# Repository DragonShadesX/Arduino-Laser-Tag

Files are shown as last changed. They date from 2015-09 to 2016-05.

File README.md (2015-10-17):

Arduino-Laser-Tag
=================

A repository for my arduino laser tag files

The idea is to create a laser tag system comparable to commercial grade systems found at arenas.

ltag_simple_tagger is a proof of concept build and is for debugging.

ltag_ fire/hit _test are also mainly for debugging.

ltag_custom_your_name_here is the only working full system code.
It is very limited and works, but it doesn't do a whole lot.  Documentation for it is in it's files.

ltag_custom_dragonshadesx is a working build of my tagger.  
So far so good.  There's a lot of comments removed right now because it's still a work in progress and I don't like sorting through it all.
Also because it's 5 in the morning and I want a backup so I can sleep well knowing my code is saved.

libraries is the local libraries you'll need for the files, the only library there right now is from:
http://www.pjrc.com/teensy/td_libs_IRremote.html
This is a modified version of the library originally found at
http://www.righto.com/2009/08/multi-protocol-infrared-remote-library.html
You'll need to replace whatever libraries you have (IRRemoteRobot or whatever) with this if you're using a standard arduino (uno, due, etc).
If you're using a teensy it should come with it's own libraries, just make sure to install them when you run the teensyduino addon.

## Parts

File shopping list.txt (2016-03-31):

	 -s teensy x5 (4tag, 2base, 1admin)
	 -s audio shield x4
	 -s audio amps

 -m 3.3vreg
 -s diodes
	 -a usd card
	 -m speakers x8
 -m shift registers x16
 -m shift registers in x4
	 -s rgb led x64
 -m resistors for LEDs xlots (for rgb, bar graphs, and 7segs)
 -s led bar graphs xseveral (Alan -blue green) (Jake -blue yellow)
 -s led 7 segs xfew
	 -m irleds x7
	 -m irrecvs x27
 -s limit switches x8
 -m usb 3.o type a ports x12 
	 -s lcd display x1
	 -o d-pad x1
	 -a rechargables x4
 -m AA holder (single) x5
	 -o AAs x8
	 -s pager motors x4
	 -m irf520-510 x7
 -a usb 3.0 3ft cables (type a - type a)
usb micro plug
 -s 5pin ribbon cable

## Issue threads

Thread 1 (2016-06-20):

EDA replacements by a free one

psykauze, 2016-06-20:
Dear DragonShadesX,

This project is very interesting and I would like to participate on this but I'm not in love with Eagle (due to it's proprietary license).

So, I want to know if you're planning to use an other EDA.

I'm used to use KiCad (due to it's similarities with Eagle) but there's also others tools. Here, 3 tools:
- gEDA: Full suite of electronic tools. It have a lot of features and also a great simulating tool (ngspice).
- KiCad: Eagle clone with a lot of libraries. There's also a 3D viewer for PCB. For simulation it can use any "spice-like" tool (like ngspice from gEDA project)
- Fritzing: There's a "breadboard" tool. It seems it can't simulate anything but I'm not sure.

Which one do you prefer ? Would you want some help for the conversion ?

Sincerely.

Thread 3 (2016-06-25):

LED Control

DragonShadesX, 2016-06-25:
Something is odd with controlling the RGB LEDs.  Honestly don't know exactly what, could never get the blue or green to light up independently.  Red LED doesn't want to light up.  All can be lit manually, so my best guess is a fried shift register or torn trace on the board but I don't have spare to test with right now.  Also possible I have something wrong in the code, but I don't know.

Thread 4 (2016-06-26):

Code: Phoenix Compatibility

DragonShadesX, 2016-06-26:
It takes 1-3 seconds between shots for the library to "reset" and fire the correct data sequence.  If you fire too fast it just sends junk data.  I'm not sure why as the Phoenix Compatible Library was not written by us.  Fix is probably to re-write or throw in a delay as a short term fix until someone wants to figure out why.  Phoenix compatibility was a side goal though, so this is low priority.

psykauze, 2016-06-27:
I don't know if it is related, but your friend GranTotem use an old version of IRremote but last year a "send loops coding error" was fixed.

The actual IRremote project is here. https://github.com/z3t0/Arduino-IRremote Hope this will fix the issue.

DragonShadesX, 2016-06-29:
I started with that version, but we have to use a specific version that is compatible with the Teensy so we can't just go back to that.  The 1-3 second delay is a known issue with communicating with the Phoenix and I haven't seen it any other time.  Both of these mean just using that library won't fix the problem.

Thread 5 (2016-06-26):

Hardware: Phoenix Compatibility

DragonShadesX, 2016-06-26:
For some reason, the hardware in the Phoenix is only triggered when the custom tagger is within a few feet of the Phoenix.  Best guess is that the IR LED is not bright enough.  This could be fixed with a stronger IR LED (not recommended) or an IR-Permeable lens to focus the light and condense the beam, though this means the user will have to be much more accurate.  This is low priority since Phoenix compatibility is not a main feature.

psykauze, 2016-06-26:
You can focusing the IR beam by using a lens.

I think this is possible with a 45mm long black tube, a lens from Google Cardboard (<$3) and a TSAL6100 (<$1). This will focus the beam into a 16mm diameter cilinder.

If you use a TSAL6200 you should have a "45mm focal" lens of more than 26mm diameter. The diameter of the beam will be 26,3mm diameter.

DragonShadesX, 2016-06-26:
I know, I've done the math and checked the numbers with a few cheap lenses.  Testing with the Phoenix taggers and the TSAL6100 with no lenses gave me the same performance with respect to how far off the target I could aim and still have the target register a hit.

Also, consider that your target (on the Phoenix) is a small, moving, ~3cm diameter dome, and with a lens/beam setup you are trying to hit it with a 2.6cm wide beam at ranges of 3-40m(max range I was able to test).  For a normal person that is near impossible, never mind when the target is a 4mm x 4mm square on the vest (if the player is trying to tag another player using the custom system).

psykauze, 2016-06-27:
You're right, I've forgot the Phoenix system use a single shot gameplay.
1) Maybe if the Soft tries to spam the shoot during ~500ms the accuracy will not improve but there's more chances to hit.
2) Reducing the beam to 10° with a lens will improve range and the need of accuracy should be correct.
3) Use of laser dot ? (In case of 13mm cilinder beam. Is it cheating ???)

psykauze, 2016-06-27:
Also, which wavelength use the Phoenix system ? Maybe it is more effective with a 850nm IR than a 940nm.

psykauze, 2016-06-27:
You could also mesure the Phoenix beam by shooting on a white board and view it with a digital camera.

psykauze, 2016-06-27:
Here some patents about Phoenix toys:
- http://www.google.com/patents/US5904621 Protocol frequency is about 38kHz
- http://www.google.com/patents/US6302796 The current drawn by the IR-LED of this presented gun is at about 3Amps. (300ft range)
- http://www.google.com/patents/US5672108 This gun use a EL-8L IR Led that emits a 940nm light. Also, this patent recommends a beam of 4°.

DragonShadesX, 2016-06-29:
First comment:
1) It doesn't send correct data so you can't hit the target, not sure what that has to do with accuracy.
2) The LED has a viewing angle of 10 degrees already.
3) If you feel like it.  I was going to avoid it because point lasers at the shoulder plates is dangerously close to someone's eyes.
Third comment:
I made some night vision goggles to help test with the project, they worked well.  Most digital cameras block IR since it messes with the pictures.
Fourth comment:
The EL-8L is a 30 degree .1 amp LED.  Also amps =/= range, and there is no way that these work at 300ft.  In testing the Phoenix dropped off at about 80ft in outdoor environments with relatively fresh batteries (~30 mins light useage).  38kHz is also pretty common, though the Phoenix do use it.
Those patents are also from almost 20 years ago and not likely to be very relevant to the Phoenix.  The third seems to have preliminary designs for the Laser Tag Team Ops gear, which is the Phoenix's predecessor (and it's sorta compatible too).  I wouldn't bother with the patents.

psykauze, 2016-06-29:
Sorry for the spam on this thread.

I've seen that the Phoenix LazerTag was based to the Tiger/Hasbro systems that was commercialized in 2004 (for Team Ops) maybe before. So it's why I've checked some technical informations about these systems also from patents.

I understand that the patents is not the reality, but they give us some clues on how the system works.

In the second patent, there's no info about the IR-LED or beam but the schematics show the IR-LED powered by a 6V battery, limited by a 1ohm resistor and drived by a bipolar transistor, so if I consider a voltage drop of 3V for transistor and IR diode, the peak current consumption is about 3Amps and can explain the 300ft range. (I know I can't be precise for the voltage drop. I've found the Vdrop should be just a little less than 4V, so the current should be a little higher than 2Amps peak.).

The third patent give some recommendations like the beam cone of 4° (adjusted by a lens) and the LED used in this patent (the EL-8L). For the last thing, we can conclude the system use a 940nm IR protocol.

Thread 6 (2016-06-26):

Hardware: Power Requirements

DragonShadesX, 2016-06-26:
The system only works with an Arduino Teensy 3.2 and 5V battery pack plugged into the Teensy.  The chosen Voltage Regulator does not output enough amps to power the Teensy and all the LEDs.  While we didn't notice any brown-outs the LEDs were dim and we barely tested it with the VReg after that.  A new, higher power VReg should fix the issue, though the socket for it might need to change.

psykauze, 2016-06-27:
Leds and IR-led don't need a voltage regulated power, just a current limitation (like a resistor).
I know you're using the integrated Teensy output pin current limitation to drive your leds but you can increase (or decrease) the leds number without burning Leds, Vreg or Teensy if you choose to drive transistors.

DragonShadesX, 2016-06-29:
LEDs will draw as much current as they need if you give them the proper voltage with enough current, so current limitation is not needed.
All LEDs are toggled by transistor (IRF5X0 or shift register), the only pin on the Teensy that is used is the 3.3v regulated output for power.

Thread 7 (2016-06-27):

Hardware: Reverse voltage protection

psykauze, 2016-06-27:
I've seen two diodes at the Power connector. If the purpose of those diode is to protect from a reverse polarity, one diode is enough.

You could also use a "poka-yoke" connector to prevent users errors.

Also, "I think" all the parts used on the board is y et reversed protected (Teensy, Leds, etc...).

DragonShadesX, 2016-06-29:
Yes we could probably use one diode, yes we could use a connector but the idea was to solder on a 9V battery connector so we didn't bother to add connector.
Not sure about the reverse protection, but either way too high voltage applied backwards will fry/brick them so we decided to make it foolproof.

psykauze, 2016-06-29:
What do you mean by "too high voltage applied backwards" ?

Do you mean you want to protect the battery of reverse current ? In this case, I still think one diode is enough and you'll gain some precious Watts (and battery capacity).

DragonShadesX, 2016-06-29:
One is probably enough, my thinking was that I wanted to make it foolproof so if someone connected the battery backwards the instant potential across the LEDs/powering the Teensy in the wrong direction couldn't damage anything.  I already bricked two Arduinos in other projects under normal usage (probably a bad power supply) and I didn't have time to get spares, so I didn't want to take chances.
The other reason is because this whole project was put together by a few people who had never really done this before, so I wanted to build in some safeties for if/when something went wrong (especially near the batteries in case we switched to LiPos).  For a final version?  Might take it out after I do some more research.  For a prototype and learning experience?  I had a bunch of those diodes on hand and it didn't cost me anything, so I figured why not.

psykauze, 2016-06-29:
Ok, not a problem. It's not a real issue because it should work like this. I'm just used to see only one diode to prevent "reverse polarity" issues. It's only because you will have a 2V Vdrop.

Also 1N4001 diodes are not very good (but very cheap). If you want to tune this part, you can use a Schottky rectifier diode as a replacement.

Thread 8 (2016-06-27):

[Enhancement]LCD screen support.

psykauze, 2016-06-27:
This is a feature request for more visibility.

DragonShadesX, 2016-06-29:
Not sure I understand?

psykauze, 2016-06-29:
It's just because the Phoenix Lazer Tag system has a LCD screen for configuration and display. This is a low priority.

DragonShadesX, 2016-06-29:
The Team Ops gear does, the Phoenix has two 5-segment LED Bar Graphs.

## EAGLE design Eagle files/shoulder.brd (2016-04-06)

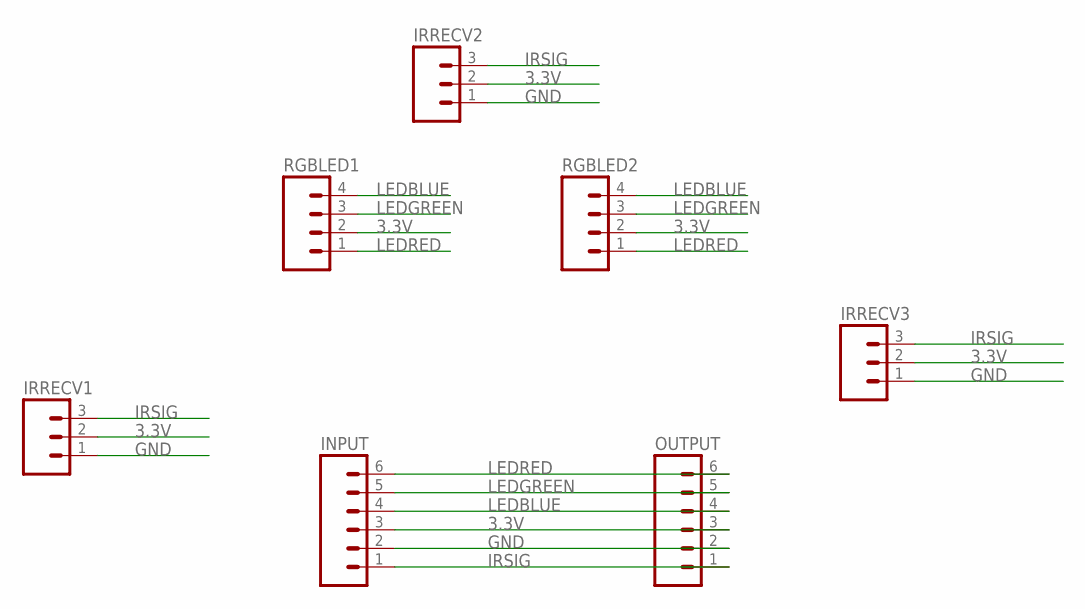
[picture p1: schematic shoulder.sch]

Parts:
INPUT: M06SILK_FEMALE_PTH; 1X06
IRRECV1, IRRECV2, IRRECV3: M03PTH; 1X03
OUTPUT: M06SILK_FEMALE_PTH; 1X06
RGBLED1, RGBLED2: M04PTH; 1X04

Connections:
3.3V: INPUT.3, IRRECV1.2, IRRECV2.2, IRRECV3.2, OUTPUT.3, RGBLED1.2, RGBLED2.2
GND: INPUT.2, IRRECV1.1, IRRECV2.1, IRRECV3.1, OUTPUT.2
IRSIG: INPUT.1, IRRECV1.3, IRRECV2.3, IRRECV3.3, OUTPUT.1
LEDBLUE: INPUT.4, OUTPUT.4, RGBLED1.4, RGBLED2.4
LEDGREEN: INPUT.5, OUTPUT.5, RGBLED1.3, RGBLED2.3
LEDRED: INPUT.6, OUTPUT.6, RGBLED1.1, RGBLED2.1

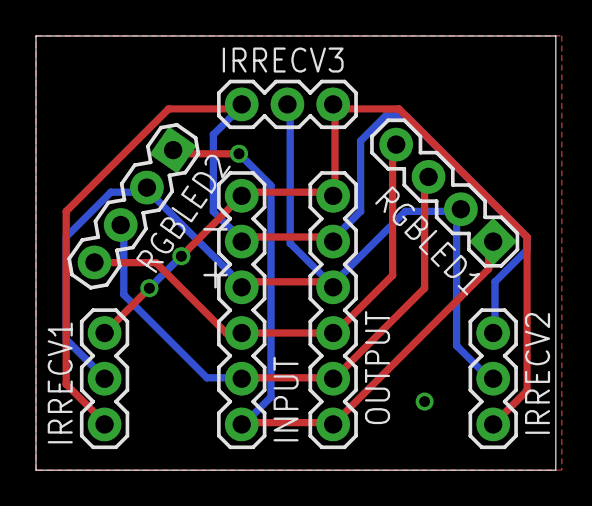
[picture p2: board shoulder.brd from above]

Board: 2 copper layers, 28.9 x 24.1 mm, 7 parts (0 on the bottom side), 6 nets.

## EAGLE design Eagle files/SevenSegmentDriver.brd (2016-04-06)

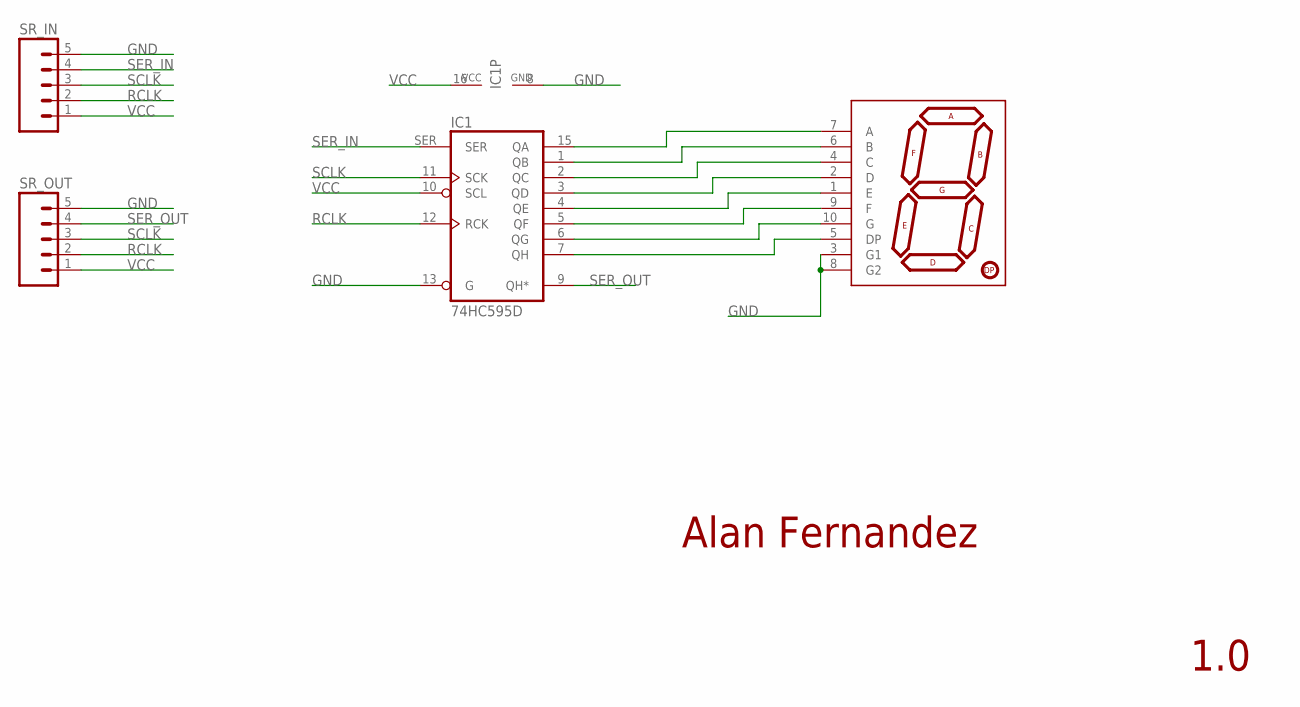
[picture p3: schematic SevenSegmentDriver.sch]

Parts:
IC1: 74HC595D; SO16
SR_IN: M05PTH; 1X05
SR_OUT: M05PTH; 1X05
U$1: 7-SEGMENT-DISPLAY-1"-REDEZ; 7-SEGMENT-1"PTH-EZ

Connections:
GND: IC1.8 (GND), IC1.13 (G), SR_IN.5, SR_OUT.5, U$1.3 (G1), U$1.8 (G2)
unnamed: IC1.15 (QA), U$1.7 (A)
unnamed: IC1.1 (QB), U$1.6 (B)
unnamed: IC1.2 (QC), U$1.4 (C)
unnamed: IC1.3 (QD), U$1.2 (D)
unnamed: IC1.4 (QE), U$1.1 (E)
unnamed: IC1.5 (QF), U$1.9 (F)
unnamed: IC1.6 (QG), U$1.10 (G)
unnamed: IC1.7 (QH), U$1.5 (DP)
RCLK: IC1.12 (RCK), SR_IN.2, SR_OUT.2
SCLK: IC1.11 (SCK), SR_IN.3, SR_OUT.3
SER_IN: IC1.SER, SR_IN.4
SER_OUT: IC1.9 (QH*), SR_OUT.4
VCC: IC1.10 (SCL), IC1.16 (VCC), SR_IN.1, SR_OUT.1

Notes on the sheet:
Alan Fernandez
1.0

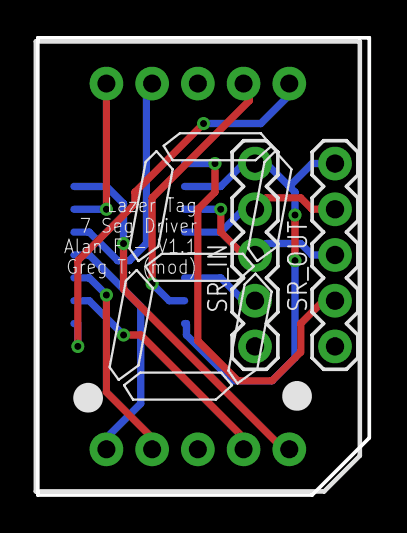
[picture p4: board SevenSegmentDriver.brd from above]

Board: 2 copper layers, 18.4 x 25.4 mm, 4 parts (1 on the bottom side), 14 nets.

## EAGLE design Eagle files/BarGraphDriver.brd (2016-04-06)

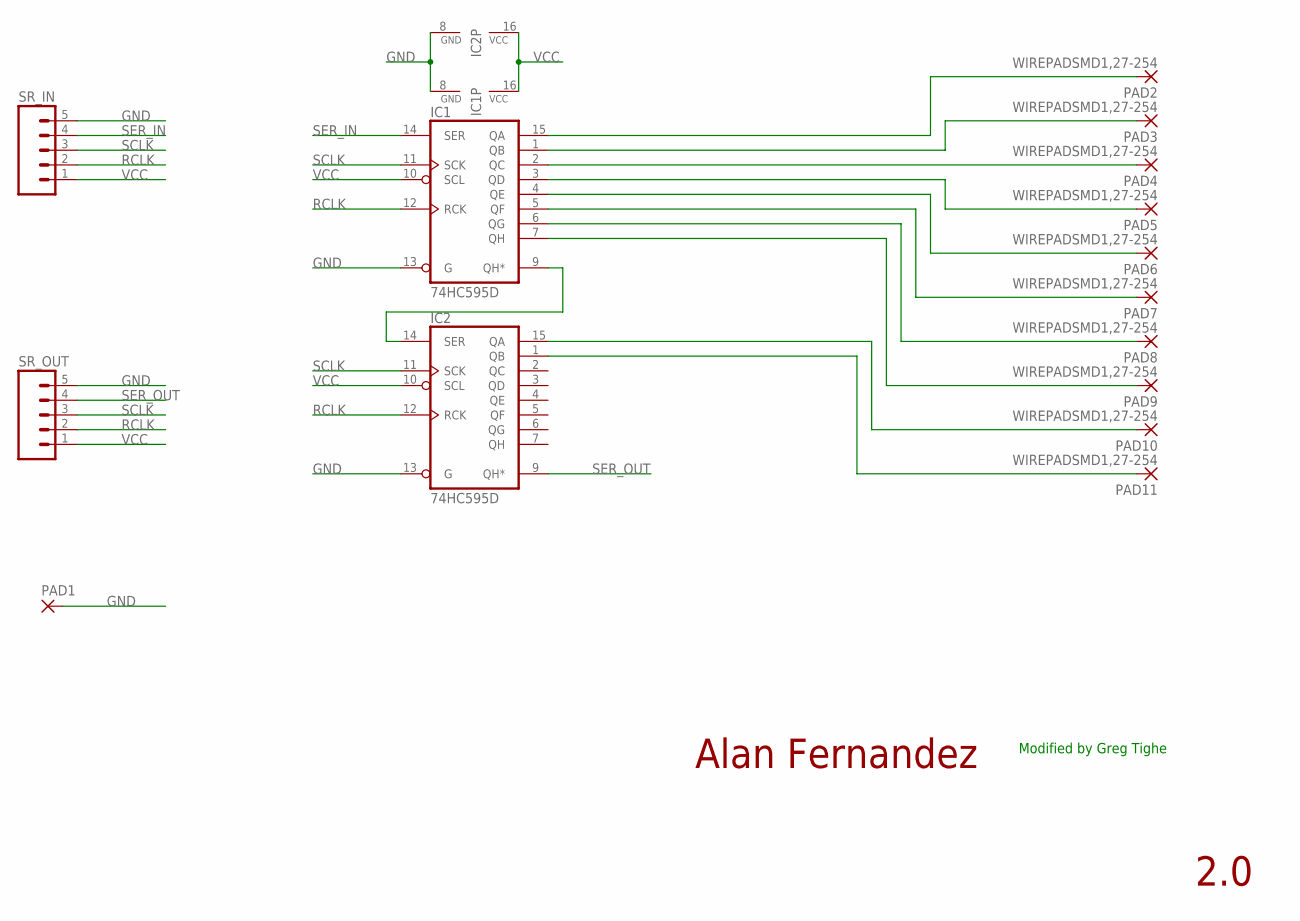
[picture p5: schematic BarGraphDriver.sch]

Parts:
IC1, IC2: 74HC595D; SO16
PAD1: SMD2; SMD1,27-2,54
PAD2, PAD3, PAD4, PAD5, PAD6, PAD7, PAD8, PAD9, PAD10, PAD11: WIREPADSMD1,27-254; SMD1,27-2,54
SR_IN: M05PTH; 1X05
SR_OUT: M05PTH; 1X05

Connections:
GND: IC1.8 (GND), IC1.13 (G), IC2.8 (GND), IC2.13 (G), PAD1.1, SR_IN.5, SR_OUT.5
unnamed: IC2.1 (QB), PAD11.1
unnamed: IC1.15 (QA), PAD2.1
unnamed: IC1.1 (QB), PAD3.1
unnamed: IC1.2 (QC), PAD4.1
unnamed: IC1.3 (QD), PAD5.1
unnamed: IC1.4 (QE), PAD6.1
unnamed: IC1.5 (QF), PAD7.1
unnamed: IC1.6 (QG), PAD8.1
unnamed: IC1.7 (QH), PAD9.1
unnamed: IC2.15 (QA), PAD10.1
unnamed: IC1.9 (QH*), IC2.14 (SER)
RCLK: IC1.12 (RCK), IC2.12 (RCK), SR_IN.2, SR_OUT.2
SCLK: IC1.11 (SCK), IC2.11 (SCK), SR_IN.3, SR_OUT.3
SER_IN: IC1.14 (SER), SR_IN.4
SER_OUT: IC2.9 (QH*), SR_OUT.4
VCC: IC1.10 (SCL), IC1.16 (VCC), IC2.10 (SCL), IC2.16 (VCC), SR_IN.1, SR_OUT.1

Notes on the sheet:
Alan Fernandez
2.0
Modified by Greg Tighe

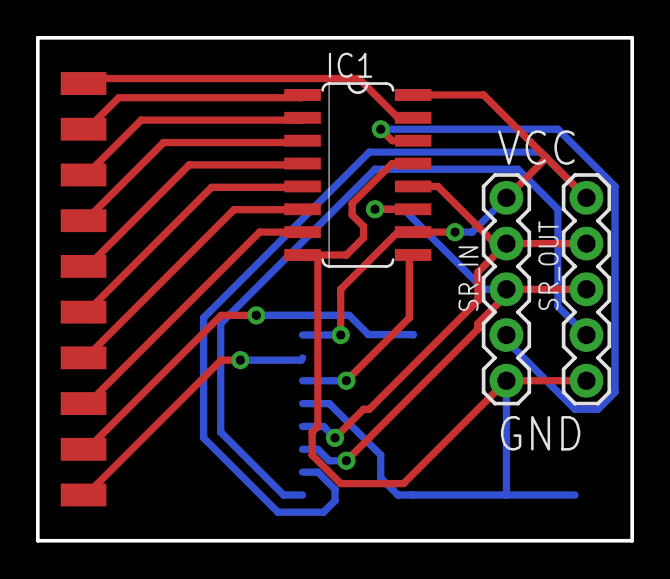
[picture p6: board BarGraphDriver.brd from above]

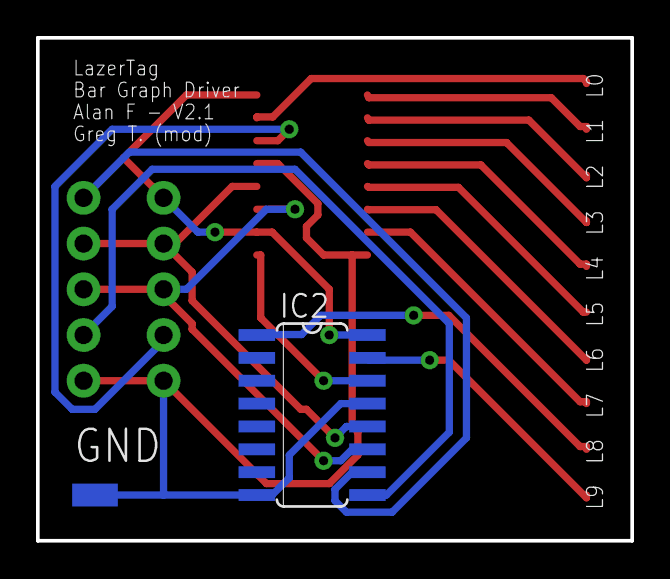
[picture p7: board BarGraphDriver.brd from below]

Board: 2 copper layers, 33.0 x 27.9 mm, 15 parts (2 on the bottom side), 17 nets.

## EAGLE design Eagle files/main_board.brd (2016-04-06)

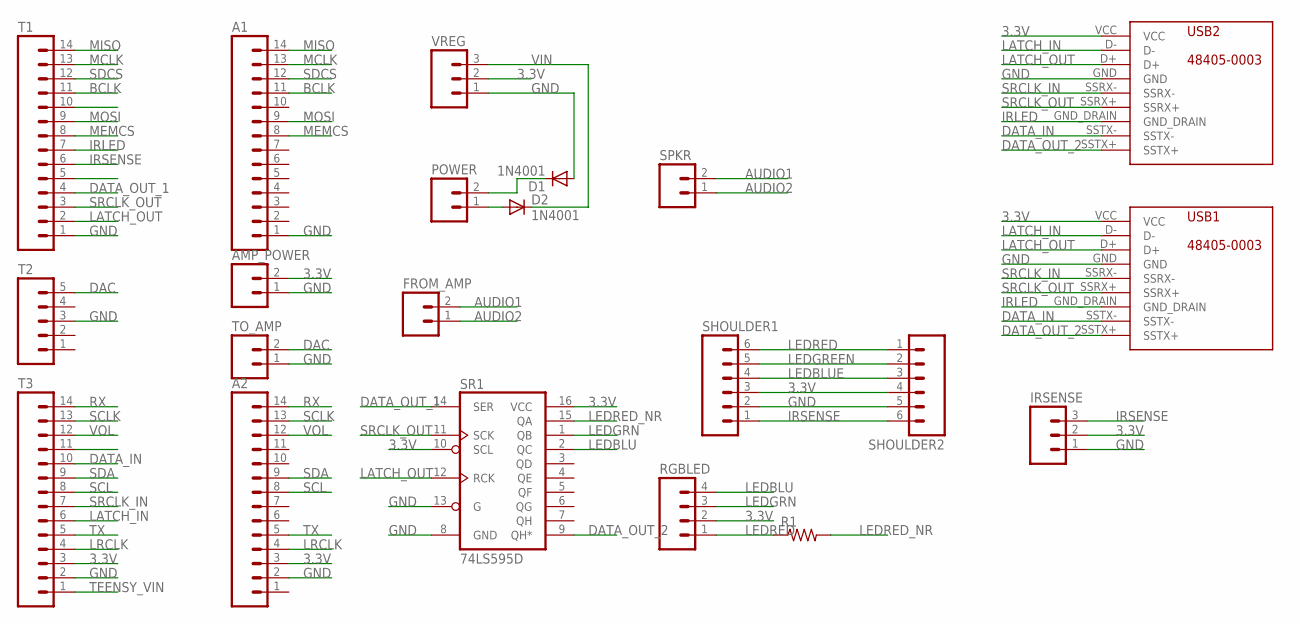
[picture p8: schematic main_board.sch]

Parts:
A1, A2: M14; 1X14
AMP_POWER: M02PTH; 1X02
D1, D2: 1N4001; DO41-10
FROM_AMP: M02PTH; 1X02
IRSENSE: M03PTH; 1X03
POWER: M02PTH; 1X02
R1: RESISTOR1206; 1206
RGBLED: M04PTH; 1X04
SHOULDER1, SHOULDER2: M06SILK_FEMALE_PTH; 1X06
SPKR: M02PTH; 1X02
SR1: 74LS595D; SO16
T1, T3: M14; 1X14
T2: M05PTH; 1X05
TO_AMP: M02PTH; 1X02
USB1, USB2: 48405-0003; 48405-0003MYVERSION
VREG: M03PTH; 1X03

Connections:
3.3V: A2.3, AMP_POWER.2, IRSENSE.2, RGBLED.2, SHOULDER1.3, SHOULDER2.4, SR1.10 (SCL), SR1.16 (VCC), T3.3, USB1.VCC, USB2.VCC, VREG.2
AUDIO1: FROM_AMP.2, SPKR.2
AUDIO2: FROM_AMP.1, SPKR.1
BCLK: A1.11, T1.11
DAC: T2.5, TO_AMP.2
DATA_IN: T3.10, USB1.SSTX-, USB2.SSTX-
DATA_OUT_1: SR1.14 (SER), T1.4
DATA_OUT_2: SR1.9 (QH*), USB1.SSTX+, USB2.SSTX+
GND: A1.1, A2.2, AMP_POWER.1, D1.A, IRSENSE.1, SHOULDER1.2, SHOULDER2.5, SR1.8 (GND), SR1.13 (G), T1.1, T2.3, T3.2, TO_AMP.1, USB1.GND, USB2.GND, VREG.1
IRLED: T1.7, USB1.GND_DRAIN, USB2.GND_DRAIN
IRSENSE: IRSENSE.3, SHOULDER1.1, SHOULDER2.6, T1.6
LATCH_IN: T3.6, USB1.D-, USB2.D-
LATCH_OUT: SR1.12 (RCK), T1.2, USB1.D+, USB2.D+
LEDBLU: RGBLED.4, SR1.2 (QC)
LEDBLUE: SHOULDER1.4, SHOULDER2.3
LEDGREEN: SHOULDER1.5, SHOULDER2.2
LEDGRN: RGBLED.3, SR1.1 (QB)
LEDRED: R1.1, RGBLED.1, SHOULDER1.6, SHOULDER2.1
LEDRED_NR: R1.2, SR1.15 (QA)
LRCLK: A2.4, T3.4
MCLK: A1.13, T1.13
MEMCS: A1.8, T1.8
MISO: A1.14, T1.14
MOSI: A1.9, T1.9
unnamed: D2.A, POWER.1
unnamed: D1.C, POWER.2
RX: A2.14, T3.14
SCL: A2.8, T3.8
SCLK: A2.13, T3.13
SDA: A2.9, T3.9
SDCS: A1.12, T1.12
SRCLK_IN: T3.7, USB1.SSRX-, USB2.SSRX-
SRCLK_OUT: SR1.11 (SCK), T1.3, USB1.SSRX+, USB2.SSRX+
TEENSY_VIN: T3.1
TX: A2.5, T3.5
VIN: D2.C, VREG.3
VOL: A2.12, T3.12

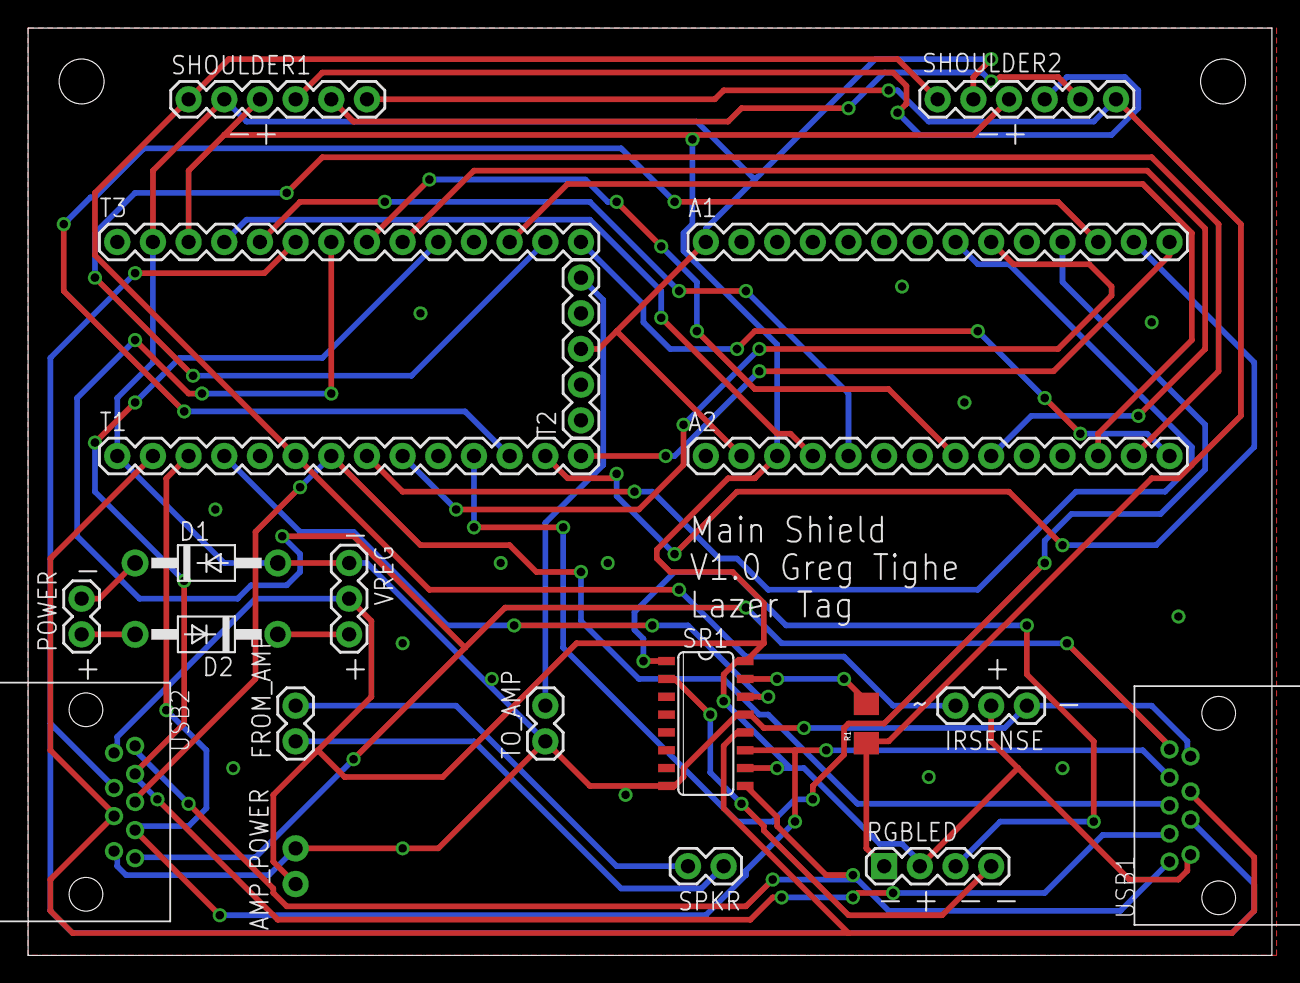
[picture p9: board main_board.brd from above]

Board: 2 copper layers, 88.6 x 66.0 mm, 21 parts (1 on the bottom side), 36 nets.

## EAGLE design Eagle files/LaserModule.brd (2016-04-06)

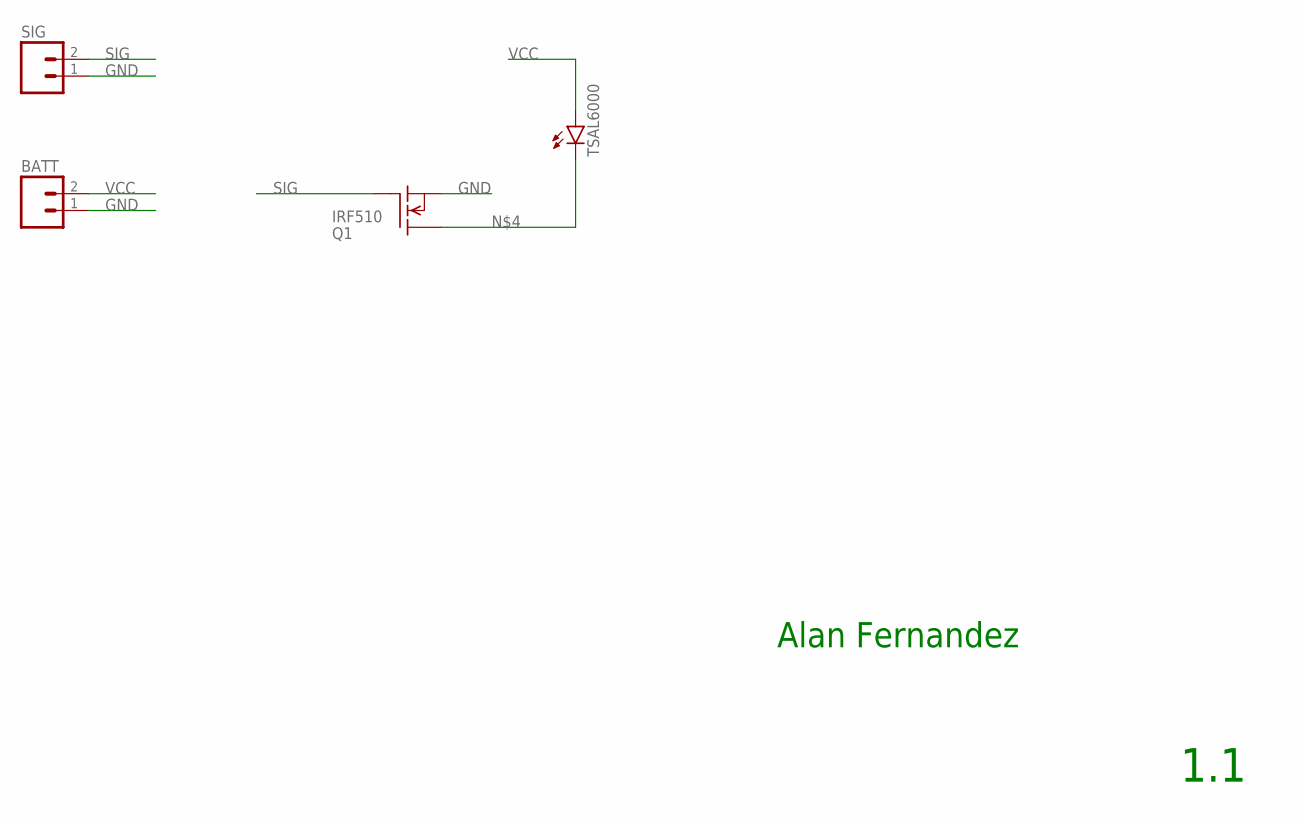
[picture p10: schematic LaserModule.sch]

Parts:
BATT: M02PTH; 1X02
Q1: IRF510; TO220
SIG: M02PTH; 1X02
TSAL6000: LED5MM

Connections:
GND: BATT.1, Q1.3 (S), SIG.1
unnamed: Q1.2 (D), TSAL6000.K (C)
SIG: Q1.1 (G), SIG.2
VCC: BATT.2, TSAL6000.A

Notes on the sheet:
Alan Fernandez
1.1

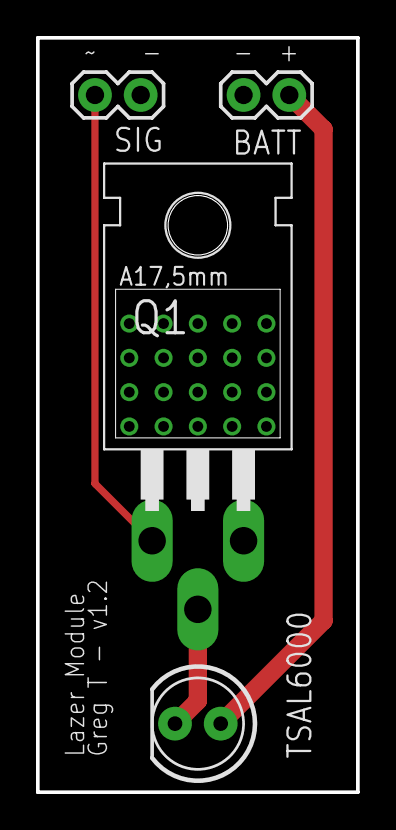
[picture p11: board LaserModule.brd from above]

Board: 2 copper layers, 17.8 x 41.9 mm, 4 parts (0 on the bottom side), 4 nets.

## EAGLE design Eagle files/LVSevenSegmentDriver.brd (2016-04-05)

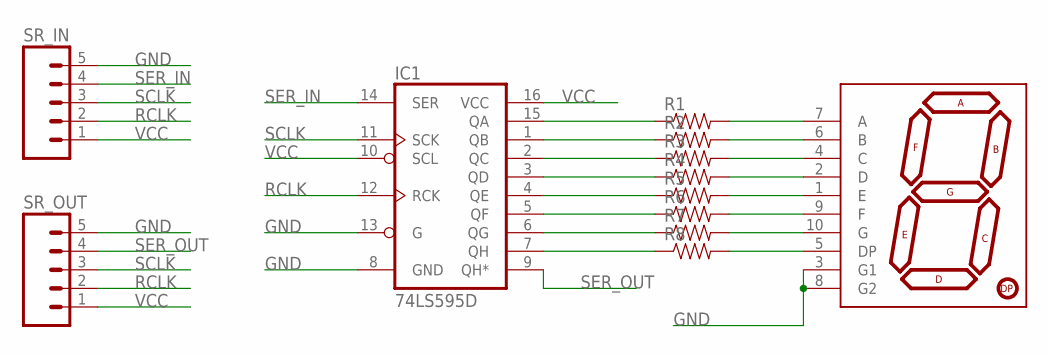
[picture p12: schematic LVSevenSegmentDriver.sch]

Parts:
IC1: 74LS595D; SO16
R1, R2, R3, R4, R5, R6, R7, R8: RESISTOR1206; 1206
SR_IN: M05PTH; 1X05
SR_OUT: M05PTH; 1X05
U$1: 7-SEGMENT-DISPLAY-1"-REDEZ; 7-SEGMENT-1"PTH-EZ

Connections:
GND: IC1.8 (GND), IC1.13 (G), SR_IN.5, SR_OUT.5, U$1.3 (G1), U$1.8 (G2)
unnamed: IC1.15 (QA), R1.1
unnamed: R1.2, U$1.7 (A)
unnamed: IC1.1 (QB), R2.1
unnamed: R2.2, U$1.6 (B)
unnamed: IC1.2 (QC), R3.1
unnamed: R3.2, U$1.4 (C)
unnamed: IC1.3 (QD), R4.1
unnamed: R4.2, U$1.2 (D)
unnamed: IC1.4 (QE), R5.1
unnamed: R5.2, U$1.1 (E)
unnamed: IC1.5 (QF), R6.1
unnamed: R6.2, U$1.9 (F)
unnamed: IC1.6 (QG), R7.1
unnamed: R7.2, U$1.10 (G)
unnamed: IC1.7 (QH), R8.1
unnamed: R8.2, U$1.5 (DP)
RCLK: IC1.12 (RCK), SR_IN.2, SR_OUT.2
SCLK: IC1.11 (SCK), SR_IN.3, SR_OUT.3
SER_IN: IC1.14 (SER), SR_IN.4
SER_OUT: IC1.9 (QH*), SR_OUT.4
VCC: IC1.10 (SCL), IC1.16 (VCC), SR_IN.1, SR_OUT.1



Board: 2 copper layers, 19.1 x 26.7 mm, 12 parts (3 on the bottom side), 22 nets.

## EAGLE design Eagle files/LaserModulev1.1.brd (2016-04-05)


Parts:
GND_BATT: WIREPAD2,54/1,1; 2,54/1,1
GND_IN: WIREPAD2,54/1,1; 2,54/1,1
Q1: IRF510; TO220
SINGAL_IN: WIREPAD2,54/1,1; 2,54/1,1
TSAL6000: LED5MM
VCC_BATT: WIREPAD2,54/1,1; 2,54/1,1

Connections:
GND: GND_BATT.1, GND_IN.1, Q1.3 (S)
unnamed: Q1.1 (G), SINGAL_IN.1
unnamed: TSAL6000.A, VCC_BATT.1
unnamed: Q1.2 (D), TSAL6000.K (C)

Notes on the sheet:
Alan Fernandez
1.1


Board: 2 copper layers, 100.0 x 80.0 mm, 6 parts (0 on the bottom side), 4 nets.

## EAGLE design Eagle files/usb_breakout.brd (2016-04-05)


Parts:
LAZER: M02PTH; 1X02
SR_IN: M05PTH; 1X05
SR_OUT: M05PTH; 1X05
USB1: 48405-0003; 48405-0003MYVERSION

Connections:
DATA_IN: SR_IN.4, USB1.SSTX-
DATA_OUT: SR_OUT.4, USB1.SSTX+
GND: LAZER.1, SR_IN.5, SR_OUT.5, USB1.GND
LZR_SIG: LAZER.2, USB1.GND_DRAIN
RCLK_IN: SR_IN.2, USB1.D-
RCLK_OUT: SR_OUT.2, USB1.D+
SRCLK_IN: SR_IN.3, USB1.SSRX-
SRCLK_OUT: SR_OUT.3, USB1.SSRX+
VCC: SR_IN.1, SR_OUT.1, USB1.VCC


Board: 2 copper layers, 21.3 x 35.5 mm, 4 parts (0 on the bottom side), 9 nets.

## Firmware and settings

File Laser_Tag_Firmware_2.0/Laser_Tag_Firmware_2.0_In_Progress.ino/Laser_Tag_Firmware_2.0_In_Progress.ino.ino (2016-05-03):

/*
   LazerTag Main Functions
   Version 1.0
   Authors: Alan Fernandez, Greg Tighe, Jake Hawes
   Last Edited: 1/5/16

   Notes:
   Decoding: DO NOT DECODE THE FIRST TWO BYTES OR THE LAST ONE. These contain team number and ID and should remain as 0-15.
*/

#include <IRremote.h>
#include <Audio.h>
#include <Wire.h>
#include <SPI.h>
#include <SD.h>
#include <SerialFlash.h>

/////////////////////
// Audio Things :3 //
/////////////////////

//AudioPlaySdWav           playWav1;
// Use one of these 3 output types: Digital I2S, Digital S/PDIF, or Analog DAC
//AudioOutputI2S           audioOutput;
//AudioOutputSPDIF       audioOutput;
//AudioOutputAnalog      audioOutput;
//AudioConnection          patchCord1(playWav1, 0, audioOutput, 0);
//AudioConnection          patchCord2(playWav1, 1, audioOutput, 1);
//AudioControlSGTL5000     sgtl5000_1;

// Use these with the audio adaptor board
#define SDCARD_CS_PIN    10
#define SDCARD_MOSI_PIN  7
#define SDCARD_SCK_PIN   14

// grabbed these from Greg's code; not sure if pin numbers changed
#define SHIFT_REGISTER_DATA_PIN  2
#define SHIFT_REGISTER_CLOCK_PIN  1
#define SHIFT_REGISTER_LATCHCLOCK  0

// IR setup
int RECV_PIN = 4;
IRsend irsend;
IRrecv irrecv(RECV_PIN);
decode_results results;

// pins
int trigger_pin = 21;
int reload_pin  = 20;
int light_pin   = 17;

//////////////////////////
// Initialize Variables //
//////////////////////////

//byte packetA[7];
//byte team     = 0x0;
//byte set_team = 0x0;
//byte max_hp   = 0x0;
//byte hp       = 0x0;
//byte max_ammo = 0x0;
//byte ammo     = 0x0;
//byte respawns = 0x0;
//byte reloads  = 0x0;
//byte damage   = 0x0;
//byte ID       = 0x0;
//byte amount   = 0x0;

byte packetA[7];
byte team     = 11;
byte set_team = 11;
byte max_hp   = 25;
byte hp       = 25;
byte max_ammo = 10;
byte ammo     = 10;
byte respawns = 0;
byte reloads  = 255;
byte damage   = 1;
byte ID       = 15;
byte amount   = 25;

unsigned long sendPacket; //This is what the tagger shoots

// stats
int fire_delay = 100;
bool player_dead = false;
bool received_pulse = true;
bool compatibility_enabled = false;

// timers
unsigned long last_shoot;
unsigned long last_reload;
int shoot_time = 300;
int reload_time = 1000;
bool shoot_ready = true;
bool reload_ready = true;

// displays
// 'b' for bar graph, '7' for 7 segment display
// designed to be modular; support for other display types can be coded in
char health_display_type = 'b';
int health_display_number = 1;
char ammo_display_type = 'b';
int ammo_display_number = 1;
bool team_color[3] = {false, false, false};

// for formatting display info to shift registers
byte low_hp[9] = {0x00000000, 0x00000001, 0x00000011, 0x00000111, 0x00001111, 0x00011111, 0x00111111, 0x01111111, 0x11111111};
byte high_hp[3] = {0x00000000, 0x00000001, 0x00000011};
byte low_ammo[9] = {0x00000000, 0x00000001, 0x00000011, 0x00000111, 0x00001111, 0x00011111, 0x00111111, 0x01111111, 0x11111111};
byte high_ammo[3] = {0x00000000, 0x00000001, 0x00000011};
byte red_byte = 0x001000000;
byte green_byte = 0x01000000;
byte blue_byte = 0x10000000;
byte first_out;
byte second_out;
byte third_out;
byte fourth_out;
byte fifth_out;

/////////////////////////////////
////FOR DEBUGGING AND TESTING////
/////////////////////////////////

//unsigned long results.value = 38076239; //Simulates the "results.value" variable that IRRecv returns after decoding the received packet
int count = 0;

/////////////////////////////////



void setup() {
  Serial.begin(9600);

  //Assign pins
  pinMode(trigger_pin, INPUT);
  pinMode(reload_pin, INPUT);
  pinMode(light_pin, OUTPUT);

  //Enable IR reciver
  irrecv.enableIRIn();

  //Audio setup
  //AudioMemory(8);

  // Comment these out if not using the audio adaptor board.
  // This may wait forever if the SDA & SCL pins lack
  // pullup resistors
  //sgtl5000_1.enable();
  //sgtl5000_1.volume(0.5);

  //SPI.setMOSI(SDCARD_MOSI_PIN);
  //SPI.setSCK(SDCARD_SCK_PIN);
  //if (!(SD.begin(SDCARD_CS_PIN))) {
  // stop here, but print a message repetitively
  //  while (1) {
  //    Serial.println("Unable to access the SD card");
  //    delay(500);
  //  }
  //}
}

void loop() {
  delay(5);
  //Serial.println("   ");
  //longToArray(results.value);

  //Pulse Received
<<<<<<< HEAD
    if(irrecv.decode(&results)){
      Serial.println("received pulse");
      longToArray(results.value);
      irrecv.resume();
      received_pulse = true;
      print_vars();
    }
=======
  if (irrecv.decode(&results)) {
    Serial.print("received pulse");
    longToArray(results.value);
    irrecv.resume();
    received_pulse = true;
  }
>>>>>>> origin/master

  //Hit by admin tool

  if (received_pulse && packetA[0] == 0) {
    Serial.println("Configuring tagger");
    //configure_tagger();
    received_pulse = false;
  }

<<<<<<< HEAD
  //Compatibility 
  if(received_pulse && (results.value == 1067460051)){// || results.value == 2800112845 || results.value == 2031644225 || results.value == 2159483741)){ //ffa, t1, t2, t3
    
    //if(sendPacket == 1067460051 && results.value == 1067460051){ //Player is FFA and hit by FFA
      Serial.println("Hit lol!");
=======
  //Compatibility
  if (received_pulse && compatibility_enabled && (results.value == 1067460051 || results.value == 2800112845 || results.value == 2031644225 || results.value == 2159483741)) { //ffa, t1, t2, t3

    if (sendPacket == 1067460051 && results.value == 1067460051) { //Player is FFA and hit by FFA
>>>>>>> origin/master
      hit(true);
    //}

    if (results.value != sendPacket && sendPacket != 1067460051 && results.value != 1067460051) { //Hit by non-friendly, non FFA
      hit(true);
    }
  }
<<<<<<< HEAD
  
//  //Not playing FFA, Hit by non-friendly, non-base
//  if(received_pulse && !compatibility_enabled && packetA[0] != 0 && packetA[0] <= 14 && packetA[1] != team && team != 9){ //Byte 0 is between 1 and 14 indicating a team
//    hit(false);
//  }
//
//  //Playing FFA, hit by player playing FFA
//  if(received_pulse && !compatibility_enabled && packetA[1] == 9 && team == 9){ 
//    hit(false);  
//  }
//  
//  //Hit by base
//  if (received_pulse && packetA[1] == 15 && packetA[0] == team) { //Received packet from a friendly base station
//    baseRefill();
//  }
//
//  //Prevents spamming reload
//  if (!reload_ready && millis() > last_reload + reload_time) {
//    reload_ready = true;
//  }
//
//  //Prevents spamming shooting
//  if (!shoot_ready && millis() > last_shoot + shoot_time) {
//    shoot_ready = true;
//  }
//
=======

  //Not playing FFA, Hit by non-friendly, non-base
  if (received_pulse && !compatibility_enabled && packetA[0] != 0 && packetA[0] <= 14 && packetA[1] != team && team != 9) { //Byte 0 is between 1 and 14 indicating a team
    hit(false);
  }

  //Playing FFA, hit by player playing FFA
  if (received_pulse && !compatibility_enabled && packetA[1] == 9 && team == 9) {
    hit(false);
  }

  //Hit by base
  if (received_pulse && packetA[1] == 15 && packetA[0] == team) { //Received packet from a friendly base station
    baseRefill();
  }

  //Prevents spamming reload
  if (!reload_ready && millis() > last_reload + reload_time) {
    reload_ready = true;
  }

  //Prevents spamming shooting
  if (!shoot_ready && millis() > last_shoot + shoot_time) {
    shoot_ready = true;
  }

>>>>>>> origin/master
  //Shoot
  //Only if the player is alive and is ready to shoot
//  if (digitalRead(trigger_pin) && !player_dead && reload_ready && shoot_ready) {
//    shoot();
//  }

//  //Reload
//  if (digitalRead(reload_pin) && reload_ready && !player_dead) {
//    reload();
//  }
//
  //Reset received_pulse status
  if (received_pulse) {
    received_pulse = false; //Already evaluated this hit, look for the next.
  }

  //////////////////////
  ////For debugging!////
  //////////////////////
  //  count++;
  //
  //  if (count == 1) {
  //    results.value = 575668223; //224FFFFF Shot by Team 2 player, -10hp
  //    received_pulse = true;
  //  }
  //  else if (count == 2) {
  //    results.value = 1432354815; //555FFFFF Shot by Team 5 player, -20hp
  //    received_pulse = true;
  //  }
  //  else if (count == 3) {
  //    results.value = 1609564159; //5FEFFFFF Shot by team 5 player, -100hp
  //  }
  //  if(count == 1){
  //    results.value = 2031644225; //LTX T2
  //    received_pulse = true;
  //  }
  //  else if(count == 2) {
  //    results.value = 2800112845; //LTX T1
  //    received_pulse = true;
  //  }
  //  else if(count == 3) {
  //    results.value = 2571435855; //FFA Player
  //
  //    received_pulse = true;
  //  }
  //  else if (count == 4) {
  //    results.value = 1067460051; //LTX FFA
  //    received_pulse = true;
  //  }

  //print_vars();
}


///////////////////////////
////SECONDARY FUNCTIONS////
///////////////////////////


<<<<<<< HEAD
void hit(bool compatibility){
  if(hp <= 0){
    //dead();
  }else{
    hp--;
=======
void hit(bool compatibility) {
  Serial.println(" ");
  Serial.println("Got hit");
  Serial.println(" ");
  if (compatibility && (hp == 0)) {
    hp = 0;
  } else if (compatibility && (hp > 1)) {
    hp--;
  } else if (!compatibility && (hp < hex_decoder(packetA[2]))) {
    hp = 0;
  } else if (!compatibility && (hp > hex_decoder(packetA[2]))) {
    hp = hp - hex_decoder(packetA[2]);
  }

  if (hp <= 0) {
    Serial.println(" ");
    Serial.println("Dead!");
    Serial.println(" ");
    dead();
>>>>>>> origin/master
  }

//  Serial.println(" ");
//  Serial.println("Got hit");
//  Serial.println(" ");
//  if(compatibility && (hp == 0)){
//    hp=0;
//  }else if(compatibility && (hp > 1)){
//    hp--;
//  }else if(!compatibility && (hp < hex_decoder(packetA[2]))){
//    hp = 0;
//  }else if(!compatibility && (hp > hex_decoder(packetA[2]))){
//    hp = hp - hex_decoder(packetA[2]);
//  }
//  
//  if(hp <= 0){
//    Serial.println(" ");
//    Serial.println("Dead!");
//    Serial.println(" ");
//    dead();
//  }
  playFile("HIT.WAV");
  update_displays(hp, ammo, team);
}


void baseRefill() {
  hp = hp + hex_decoder(packetA[3]);
  ammo = ammo + hex_decoder(packetA[4]);
  //playFile("REFILL.WAV");
  update_displays(hp, ammo, team);
}

void shoot() {
  Serial.println("Shooting!");
  if (ammo > 0) {
    irsend.sendRC6(sendPacket, 32);
    irrecv.enableIRIn();
    ammo--;
    update_displays(hp, ammo, team);
    playFile("SHOOT.WAV");
//    last_shoot = millis();
//    shoot_ready = false;
  }
  else {
    playFile("OOA.WAV");
  }
}

void reload() {
  Serial.println("Reloading!");
//  if (reloads == 255) {
//    ammo = max_ammo;
//    playFile("RELOAD.WAV");
//    last_reload = millis();
//    reload_ready = false;
//    update_displays(hp, ammo, team);
//  }
//  else 
if (reloads != 0) {
    ammo = max_ammo;
    reloads--;
    playFile("RELOAD.WAV");
    last_reload = millis();
    reload_ready = false;
    update_displays(hp, ammo, team);
  }
  else {
    playFile("OOA.WAV");
  }
}

void dead() {
  if (respawns <= 0) { //If respawns are already at 0, the player is now dead
    player_dead = true;
    playFile("DEAD.WAV");
    update_displays(0, 0, team);
  }

  else {
    Serial.println(" ");
    Serial.println("Respawning!");
    Serial.println(" ");
    respawns--; //Respawns are not yet 0, player is still alive.
    hp = 100; //Full health again
    update_displays(hp, ammo, team);
    playFile("RESPAWN.WAV");
  }
}

//Sets all the variables to those given by the admin tool
void configure_tagger() {

  //Check if receiving LTX configuration
  if (packetA[1] == 12 || packetA[1] == 13 || packetA[1] == 14 || packetA[1] == 15) { //FFA, T1, T2, T3 - Missing first byte
    compatibility_enabled = true;

    if (packetA[1] == 12) {
      sendPacket = 1067460051; //Sending LTX FFA HEX
      team       = 12;
      ID         = 15;
    } else if (packetA[1] == 13) {
      sendPacket = 2800112845; //Sending LTX T1 HEX
      team       = 13;
      ID         = 15;
    } else if (packetA[1] == 14) {
      sendPacket = 2031644225; //Sending LTX T2 HEX
      team       = 14;
      ID         = 15;
    } else if (packetA[1] == 15) {
      sendPacket = 2159483741; //Sending LTX T3 HEX
      team       = 15;
      ID         = 15;
    }

    //Stats accross all taggers playing LTX Mode
    hp       =  hex_decoder(packetA[2]);
    max_ammo =  hex_decoder(packetA[3]);
    ammo     =  hex_decoder(packetA[3]); //Reload the tagger
    respawns =  hex_decoder(packetA[4]);
    reloads  =  hex_decoder(packetA[5]);
    damage   =  hex_decoder(packetA[6]);


  } else {
    compatibility_enabled = false;

    team     =  packetA[1];
    hp       =  hex_decoder(packetA[2]);
    max_ammo =  hex_decoder(packetA[3]);
    ammo     =  hex_decoder(packetA[3]); //Reload the tagger
    respawns =  hex_decoder(packetA[4]);
    reloads  =  hex_decoder(packetA[5]);
    damage   =  hex_decoder(packetA[6]);
    ID       =  packetA[7];

    //*********************Create the Custom Packet for this Tagger*********************

    //    byte teamEncoded     = constrain(packetA[1], 0x0, 0xf);
    //    byte hpEncoded       = constrain(packetA[2], 0x0, 0xf);
    //    byte ammoEncoded     = constrain(packetA[3], 0x0, 0xf);
    //    byte respawnsEncoded = constrain(packetA[4], 0x0, 0xf);
    //    byte reloadsEncoded  = constrain(packetA[5], 0x0, 0xf);
    //    byte damageEncoded   = constrain(packetA[6], 0x0, 0xf);
    //    byte IDEncoded       = constrain(packetA[7], 0x0, 0xf);

    //sendPacket = (((unsigned long)((results.value << 4 ) & 0xFFFFFFFF) >> 4 & 0xFFFFFFFF) | ((results.value>>24 & 0xFFFFFFFF) << 28 & 0xFFFFFFFF)); //PEW PEW PEW!!
    sendPacket = (results.value & 0x0FFFFFFF) | team << 28;
  }
  update_displays(hp, ammo, team);

}



////////////////
////FEEDBACK////
////////////////

void update_displays(int d_hp, int d_ammo, byte d_team) {
  // user can add support for 7 segs and other types of displays
  // base code supports 1 bar graph for health and 1 for ammo

  digitalWrite(SHIFT_REGISTER_LATCHCLOCK, HIGH);

  // update health
  if (health_display_type == 'b') {
    // remap hp to a scale of 10 for bar graph
    d_hp = map(d_hp, 0, max_hp, 0, 10);
    byte first_out = high_hp[constrain(d_hp - 8, 0, 2)];
    byte second_out = low_hp[constrain(d_hp, 0, 8)];
  }

  else if (health_display_type == '7') {
    // update health with 7 seg
    // dependent on number of displays
  }

  // update ammo
  if (ammo_display_type == 'b') {
    // remap ammo to a scale of 10 for bar graph
    d_ammo = map(d_ammo, 0, max_ammo, 0, 10);
    byte third_out = high_ammo[constrain(d_ammo - 8, 0, 2)];
    byte fourth_out = low_ammo[constrain(d_ammo, 0, 8)];
  }

  else if (ammo_display_type == '7') {
    // update ammo count with 7 seg
    // dependent on number of displays
  }

  // update team color
  // set up fifth_out
  team_color_decoder(d_team);
  boolean red = team_color[0];
  boolean green = team_color[1];
  boolean blue = team_color[2];

  if (red) {
    fifth_out = fifth_out | red_byte;
  }
  if (green) {
    fifth_out = fifth_out | green_byte;
  }
  if (blue) {
    fifth_out = fifth_out | blue_byte;
  }

  // send out all data to fill shift registers
  shiftOut(SHIFT_REGISTER_DATA_PIN, SHIFT_REGISTER_CLOCK_PIN, MSBFIRST, first_out);
  shiftOut(SHIFT_REGISTER_DATA_PIN, SHIFT_REGISTER_CLOCK_PIN, MSBFIRST, second_out);
  shiftOut(SHIFT_REGISTER_DATA_PIN, SHIFT_REGISTER_CLOCK_PIN, MSBFIRST, third_out);
  shiftOut(SHIFT_REGISTER_DATA_PIN, SHIFT_REGISTER_CLOCK_PIN, MSBFIRST, fourth_out);
  shiftOut(SHIFT_REGISTER_DATA_PIN, SHIFT_REGISTER_CLOCK_PIN, MSBFIRST, fifth_out);

  // push data out of shift registers to update displays
  digitalWrite(SHIFT_REGISTER_LATCHCLOCK, LOW);
  delayMicroseconds(5);
  digitalWrite(SHIFT_REGISTER_LATCHCLOCK, HIGH);
  delayMicroseconds(5);

  print_vars();
}

void playFile(const char *filename)
{
  Serial.print("Playing audio file: ");
  Serial.println(filename);

  // Start playing the file.  This sketch continues to
  // run while the file plays.
  playWav1.play(filename);

  // A brief delay for the library read WAV info
  delay(5);

  // Simply wait for the file to finish playing.
  //while (playWav1.isPlaying()) {
    // uncomment these lines if you audio shield
    // has the optional volume pot soldered
    //float vol = analogRead(15);
    //vol = vol / 1024;
    // sgtl5000_1.volume(vol);
  //}
}


////////////////
////DECODING////
////////////////


//Bit shifting the individual characters into cells in the array
void longToArray(unsigned long packet) {
  packetA[7] = (packet & 0xF);
  packetA[6] = ((packet >> 4) & 0xF);
  packetA[5] = ((packet >> 8) & 0xF);
  packetA[4] = ((packet >> 12) & 0xF);
  packetA[3] = ((packet >> 16) & 0xF);
  packetA[2] = ((packet >> 20) & 0xF);
  packetA[1] = ((packet >> 24) & 0xF);
  packetA[0] = ((packet >> 28) & 0xF);
}



void team_color_decoder(byte i_team) {
  switch (i_team) {
    case 0:                             //Admin Tagger: White
      color_assigner(true, true, true);
      break;
    case 1:                             //Team 1: Red
      color_assigner(true, false, false);
      break;
    case 2:                             //Team 2: Green
      color_assigner(false, true, false);
      break;
    case 3:                             //Team 3: Blue
      color_assigner(false, false, true);
      break;
    case 4:                             //Team 4: Yellow
      color_assigner(true, true, false);
      break;
    case 5:                             //Team 5: Magenta
      color_assigner(true, false, true);
      break;
    case 6:                             //Team 6: Cyan
      color_assigner(false, true, true);
      break;
    case 7:                             //Team 7: White
      color_assigner(true, true, true);
      break;
    case 8:                             //Team 8: Red (repeat :/)
      color_assigner(true, false, false);
      break;
    case 9:                             //Free for All: White
      color_assigner(true, true, true);
      break;
    case 10:                            //Human: Blue
      color_assigner(false, false, true);
      break;
    case 11:                             //Infected: Green
      color_assigner(false, true, false);
      break;
    case 12:                             //Phoenix Free for All: White
      color_assigner(true, true, true);
      break;
    case 13:                             //Phoenix Team 1: Red
      color_assigner(true, false, false);
      break;
    case 14:                             //Phoenix Team 2: Green
      color_assigner(false, true, false);
      break;
    case 15:                             //Phoenix Team 3: Blue
      color_assigner(false, false, true);
      break;
    default:                             //Turn off if failed :/
      color_assigner(false, false, false);
      break;

  }
}

//Hack fix to change less lines of code in the above function
void color_assigner(bool first, bool second, bool third) {
  team_color[0] = first;
  team_color[1] = second;
  team_color[2] = third;
}

long hex_decoder(byte inc_hex) {
  switch (inc_hex) {
    case 0:
      return                0;
      break;
    case 1:
      return                1;
      break;
    case 2:
      return                3;
      break;
    case 3:
      return                5;
      break;
    case 4:
      return               10;
      break;
    case 5:
      return               20;
      break;
    case 6:
      return               25;
      break;
    case 7:
      return               30;
      break;
    case 8:
      return               40;
      break;
    case 9:
      return               50;
      break;
    case 10:
      return               60;
      break;
    case 11:
      return               70;
      break;
    case 12:
      return               80;
      break;
    case 13:
      return               90;
      break;
    case 14:
      return              100;
      break;
    case 15:
      return              255;
      break;
    default:
      return                0;
      break;
  }

}

/////////////////
////DEBUGGING////
/////////////////


//For debugging purposes

void print_vars() {
  Serial.println(" ");

  Serial.print("Team - Stored: ");
  Serial.print(team);
  Serial.print(" Received: ");
  Serial.println(packetA[1]);

  Serial.print("Ammo - Stored: ");
  Serial.print(ammo);
  Serial.print(" Received: ");
  Serial.println(packetA[3]);

  Serial.print("HP - Stored: ");
  Serial.print(hp);
  Serial.print(" Received: ");
  Serial.println(packetA[2]);

  Serial.print("Reloads - Stored: ");
  Serial.print(reloads);
  Serial.print(" Received: ");
  Serial.println(packetA[5]);

  Serial.print("Damage - Stored: ");
  Serial.print(damage);
  Serial.print(" Received: ");
  Serial.println(packetA[6]);

  Serial.print("ID - Stored: ");
  Serial.print(ID);
  Serial.print(" Received: ");
  Serial.println(packetA[7]);

  Serial.print("Respawns - Stored: ");
  Serial.print(respawns);
  Serial.print(" Received: ");
  Serial.println(packetA[4]);

  Serial.print("Dead: ");
  Serial.print(player_dead);
  Serial.println(" ");

  Serial.print("Compatibility: ");
  Serial.print(compatibility_enabled);
  Serial.println(" ");

  Serial.print("sendPacket: ");
  Serial.print(sendPacket);
  Serial.println(" ");

  Serial.print("receivedPacket: ");
  Serial.print(results.value);
  Serial.println(" ");
}

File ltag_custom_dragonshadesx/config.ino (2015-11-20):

/*
 * If you have any other hardware requiring physical pins, assign the pins here.
 * You will need to add the pinMode() for those pins in the setup() function in the main_code file
 * This file is also where you should initialize any random variables you wish to have control over.
 */

// include the libraries
#include <IRremote.h>
//#include <Audio.h>
//#include <Wire.h>
//#include <SPI.h>
//#include <SD.h>
//#include <SerialFlash.h>

#define LED_PIN  5 //has to be 5 for a teensy
#define RECV_PIN  4
// #define TRIGGER_PIN  20
// #define RELOAD_PIN  21
#define HAPTICS_VIBRATE_PIN  16
#define HAPTICS_SOLENOID_PIN  17
#define SHIFT_REGISTER_DATA_PIN  0
#define SHIFT_REGISTER_CLOCK_PIN  2
#define SHIFT_REGISTER_LATCHCLOCK  1
#define SHIFT_INPUT_DATA_PIN  XX
#define SHIFT_INPUT_CLOCK_PIN  XX
#define SHIFT_INPUT_LATCH_PIN  XX
#define SDCARD_CS_PIN    10
#define SDCARD_MOSI_PIN  7
#define SDCARD_SCK_PIN   14

unsigned int alert_length = 500; 
unsigned int slide_length = 200;

//------------------------------DO NOT MODIFY VARIABLES BELOW------------------------------

/*
 * These variables/classes etc. are used in vital functions of the tagger.
 * YOU MAY NOT MODIFY THEM OR THEIR VALUES ANYWHERE IN THE CODE.
 * That would be cheating.
 * And cheating is not acceptable.
 */

////audio shield setup stuffs
//AudioPlaySdWav           playWav1;
//// Use one of these 3 output types: Digital I2S, Digital S/PDIF, or Analog DAC
//AudioOutputI2S           audioOutput;
////AudioOutputSPDIF       audioOutput;
////AudioOutputAnalog      audioOutput;
//AudioConnection          patchCord1(playWav1, 0, audioOutput, 0);
//AudioConnection          patchCord2(playWav1, 1, audioOutput, 1);
//AudioControlSGTL5000     sgtl5000_1;

IRsend irsend;
IRrecv irrecv(RECV_PIN);
decode_results results;

int health = 10;
int ammo = 10;
int mag_size = 10;
boolean reloading = false;
long last_fire = 0L;
long last_hit = 0L;
long last_load = 0L;
boolean fire_ready = true;
boolean solenoid_active = false;
boolean buzzer_active = false;
booelan trigger_read = false;
boolean reload_read = false;

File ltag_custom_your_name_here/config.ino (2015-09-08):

/*
 * If you have any other hardware requiring physical pins, assign the pins here.
 * You will need to add the pinMode() for those pins in the setup() function in the main_code file
 * This file is also where you should initialize any random variables you wish to have control over.
 */

// include the library 
#include <IRremote.h>

// pin that controlls the IR LEDs 
// this should be a PWM capable pin, and on an arduino teensy must be pin 5
int LED_PIN = XX;

// pin that the IR Receiver data pin is connected to
// no special requirements
int RECV_PIN = XX;

// pin that connects to the trigger button
// button must read logic high when pressed, logic low when released
int TRIGGER_PIN = XX;

// pin that connects to the overheat LED
// LED should have appropriae resistor so the LED will not burn out
int OVERHEAT_ALERT_LED_PIN = XX;

// pin that connects to the you-are-hit LED
// LED should have appropriae resistor so the LED will not burn out
int HIT_ALERT_LED_PIN = XX;

// length of time in milliseconds that the hit alert LED should stay lit after being hit
unsigned int alert_length = XX;  //I reccomend 200

//------------------------------DO NOT MODIFY VARIABLES BELOW------------------------------

/*
 * These variables/classes etc. are used in vital functions of the tagger.
 * YOU MAY NOT MODIFY THEM OR THEIR VALUES ANYWHERE IN THE CODE.
 * That would be cheating.
 * And cheating is not acceptable.
 */

// these are variables and setup functions for the IRremote library
IRsend irsend;
IRrecv irrecv(RECV_PIN);
decode_results results;
 
// player health
int health = 10;

// used to track current tagger heat
int heat = 0;

// max heat allowed before overheat
int overheat = 10;

// stores last time fired, used for overheat and fire-rate tracking
long last_fire = 0L;

// stores last time hit, used for indicator LED
long last_hit = 0L;

// stores last cooldown for cooldown over time functionality
long last_cooldown = 0L;

// stores if tagger is overheated, used to disable tagger if overheated
boolean overheated = false;

// stores if trigger has been released since it was pressed
// used for semi-auto functionality
boolean fire_ready = true;

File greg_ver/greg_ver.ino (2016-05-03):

 //this is the last minute "I just need it to work" version of the code
//it only does FFA but it also works with the Phoenix LTX taggers

#include <IRremote.h>
#include <Audio.h>
#include <Wire.h>
#include <SPI.h>
#include <SD.h>

AudioPlaySdWav           playWav1;
// Use one of these 3 output types: Digital I2S, Digital S/PDIF, or Analog DAC
//AudioOutputI2S           audioOutput;
//AudioOutputSPDIF       audioOutput;
AudioOutputAnalog      audioOutput;
AudioConnection          patchCord1(playWav1, 0, audioOutput, 0);
AudioConnection          patchCord2(playWav1, 1, audioOutput, 1);
AudioControlSGTL5000     sgtl5000_1;

// Use these with the audio adaptor board
#define SDCARD_CS_PIN    10
#define SDCARD_MOSI_PIN  7
#define SDCARD_SCK_PIN   14

int RECV_PIN = 4;
IRsend irsend;
IRrecv irrecv(RECV_PIN);
decode_results results;

int trigger_pin = 21;
int reload_pin  = 20;
int light_pin   = 17;

int SHIFT_REGISTER_DATA_PIN = 2;
int SHIFT_REGISTER_CLOCK_PIN = 1;
int SHIFT_REGISTER_LATCHCLOCK = 0;

int hp = 25;
int max_hp = 25;
int ammo = 10;
int max_ammo = 10;

unsigned long last_shoot;
unsigned long last_reload;
int shoot_time = 200;
int reload_time = 100;
bool shoot_ready = true;
bool reload_ready = true;

byte low_hp[9] = {0b0000000, 0b00000001, 0b00000011, 0b00000111, 0b00001111, 0b00011111, 0b00111111, 0b01111111, 0b11111111};
byte high_hp[3] = {0b00000000, 0b00000010, 0b00000011};
byte low_ammo[9] = {0b0000000, 0b00000001, 0b00000011, 0b00000111, 0b00001111, 0b00011111, 0b00111111, 0b01111111, 0b11111111};
byte high_ammo[3] = {0b00000000, 0b00000010, 0b00000011};
byte red_byte = 0b00100000;
byte green_byte = 0b01000000;
byte blue_byte = 0b10000000;
byte first_out;
byte second_out;
byte third_out;
byte fourth_out;
byte fifth_out = 0x00;

unsigned long send_packet = 0x3FA025D3;

void setup() {
  Serial.begin(9600);
  // put your setup code here, to run once:
  pinMode(trigger_pin, INPUT_PULLUP);
  pinMode(reload_pin, INPUT_PULLUP);
  pinMode(light_pin, OUTPUT);
  pinMode(SHIFT_REGISTER_DATA_PIN, OUTPUT);
  pinMode(SHIFT_REGISTER_CLOCK_PIN, OUTPUT);
  pinMode(SHIFT_REGISTER_LATCHCLOCK, OUTPUT);
  irrecv.resume();
  //Audio setup
  AudioMemory(8);

  // Comment these out if not using the audio adaptor board.
  // This may wait forever if the SDA & SCL pins lack
  // pullup resistors
  sgtl5000_1.enable();
  sgtl5000_1.volume(0.5);

  SPI.setMOSI(SDCARD_MOSI_PIN);
  SPI.setSCK(SDCARD_SCK_PIN);
  if (!(SD.begin(SDCARD_CS_PIN))) {
  // stop here, but print a message repetitively
    while (1) {
      Serial.println("Unable to access the SD card");
      delay(500);
    }
  }
  playWav1.play("RESPAWN.WAV");
  delay(5);
  update_displays(hp, ammo);

}

void loop() {
  // put your main code here, to run repeatedly:
  if (irrecv.decode(&results)) {
    if (results.value == send_packet) {
      hp--;
      update_displays(hp, ammo);
      playWav1.play("HIT.WAV");
      delay(5);
    }
    irrecv.resume();
  }

  if (!digitalRead(trigger_pin) && shoot_ready ) {
    if (ammo > 0) {
      ammo--;
      //irsend.sendRC6(send_packet, 32);
      //unsigned int test_buffer[16] = {-6050, 2900, -2100, 950, -2050, 950, -2050, 900, -2050, 1000, -2000, 950, -2050, 900, -2100, 1000};
      unsigned int test_buffer[] = {6050, 2900, 2100, 950, 2050, 950, 2050, 900, 2050, 1000, 2000, 950, 2050, 900, 2100, 1000};
      irsend.sendRaw(test_buffer, 16, 38); 
      irrecv.enableIRIn();
      digitalWrite(light_pin, HIGH);
      last_shoot = millis();
      shoot_ready = false;
      update_displays(hp, ammo);
      playWav1.play("SHOOT.WAV");
      delay(5);
    }
    else {
      shoot_ready = false;
      playWav1.play("OOA.WAV");
      delay(5);    
    }
  }

  if (!digitalRead(reload_pin) && reload_ready ) {
    ammo = max_ammo;
    last_reload = millis();
    reload_ready = false;
    update_displays(hp, ammo);
    playWav1.play("RELOAD.WAV");
    delay(5);
  }

  //Prevents spamming reload
  if (!reload_ready && millis() > last_reload + reload_time) {
    reload_ready = true;
  }

  //Prevents spamming shooting
  if (!shoot_ready && millis() > last_shoot + shoot_time) {
    shoot_ready = true;
    digitalWrite(light_pin, LOW);
  }
  
  if(hp <= 0 && ((shoot_ready == true) || (reload_ready == true) ) ){
    shoot_ready = false;
    reload_ready = false;
    playWav1.play("DEAD.WAV");
    delay(5);
  }
}


void update_displays(int d_hp, int d_ammo) {
  // user can add support for 7 segs and other types of displays
  // base code supports 1 bar graph for health and 1 for ammo

  digitalWrite(SHIFT_REGISTER_LATCHCLOCK, HIGH);

  // update health
  // remap hp to a scale of 10 for bar graph
  d_hp = map(d_hp, 0, max_hp, 0, 10);
  byte first_out = high_hp[constrain(d_hp - 8, 0, 2)];
  byte second_out = low_hp[constrain(d_hp, 0, 8)];

  // update ammo
  // remap ammo to a scale of 10 for bar graph
  d_ammo = map(d_ammo, 0, max_ammo, 0, 10);
  byte third_out = high_ammo[constrain(d_ammo - 8, 0, 2)];
  byte fourth_out = low_ammo[constrain(d_ammo, 0, 8)];

  fifth_out = !(fifth_out | red_byte);
  fifth_out = !(fifth_out | green_byte);
  fifth_out = !(fifth_out | blue_byte);

  // send out all data to fill shift registers
  shiftOut(SHIFT_REGISTER_DATA_PIN, SHIFT_REGISTER_CLOCK_PIN, MSBFIRST, first_out);
  shiftOut(SHIFT_REGISTER_DATA_PIN, SHIFT_REGISTER_CLOCK_PIN, MSBFIRST, second_out);
  shiftOut(SHIFT_REGISTER_DATA_PIN, SHIFT_REGISTER_CLOCK_PIN, MSBFIRST, third_out);
  shiftOut(SHIFT_REGISTER_DATA_PIN, SHIFT_REGISTER_CLOCK_PIN, MSBFIRST, fourth_out);
  shiftOut(SHIFT_REGISTER_DATA_PIN, SHIFT_REGISTER_CLOCK_PIN, MSBFIRST, fifth_out);

  // push data out of shift registers to update displays
  digitalWrite(SHIFT_REGISTER_LATCHCLOCK, LOW);
  delayMicroseconds(5);
  digitalWrite(SHIFT_REGISTER_LATCHCLOCK, HIGH);
  delayMicroseconds(5);
}

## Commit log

2014-08-11 Rules/BOM
    Added the rules for designing a tagger and the current BOM for said
    tagger
    [LaserTagPartsList.xlsx]
2014-08-13 Fixes to 1.1
    Added burst count option, strengthened health check for "dying" and
    added a check so that the update displays function would be called only
    when health or ammo changed instead of every time the loop ran to save
    processor power.
2014-08-18 New version of tagger
    The 1.2 code removes the need for hardware control of the IR LED
    frequency and the BOM has been changed to match. (Confused? Sorry,
    I'll put up circuit diagrams soon that will make this much more clear)
    [LaserTagPartsList.xlsx]
2014-11-27 Minor changes and a new tagger
    Minor bug fixes to V1.2, such as the fact that passing a duration to
    tone() does not also count as a delay (whoops).
    The new file is a set of basic firmware for the prototype soon to be
    built inside a cheap plastic "gun" housing for a play station move
    controller. (Yeah "gun" shapes are against the rules but this allows me
    to test accuracy in a frame type I know and can aim very easily/well, as
    well as the actual casing makes it very easy to swap test LED
    configurations, so I'm using it for the prototype.)
2015-09-05 Cleaned up the repo
    Removed old and broken files, from here on out I am trying to actually
    use source control correctly.
    [LaserTagPartsList.xlsx]
2015-09-07 Custom DIY Tagger Template
    These are the files for a custom DIY tagger. Currently they compile but
    have not been tested yet. Hardware prototypes need some modifications
    before that happens, and I wanted to get these files up as soon as they
    were done. Inevitable bugfixes soon.
    [config.ino, helper_functions.ino, ltag_custom_your_name_here.ino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]
2015-09-08 Bugfixes
    The inevitable bugfixes. Everything is tested and works now.
    [config.ino, main_code.ino]
2015-09-08 Added Library
    Added the correct library and updated the README. These changes
    *should* allow anyone to clone this to their computer and use it as an
    Arduino Workspace.
2015-10-17 New tagger, library fixes (I hope)
    I finally got my tagger hardware up and running, although the haptic
    feedback is giving me loads of trouble, but this code works for now.
    Solenoid "click" feedback is disabled, everything else works. Still no
    team support yet though.
    [config.ino, helper_functions.ino, ltag_custom_dragonshadesx.ino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]
2016-03-18 Prep for ISP
    Moved a bunch of old and broken stuff out of the main folder so clean up
    the repo in preparation for the ISP
    [config.ino, helper_functions.ino, ltag_custom_dragonshadesx.ino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]
2016-03-25 New parts
    Added a few things to the shopping list I forgot in my tiredness last
    night
2016-03-31 PCBs
    Changes to shopping list, new folder added for PCBs
2016-04-01 Bar Graph Driver V 2.0
    Bar Graph Driver board and schematic.
    [BarGraphDriver.brd, BarGraphDriver.sch]
2016-04-01 Bar Graph Driver V 2.0
    Bar Graph Driver board and schematic. Ready for prototyping.
    [BarGraphDriver.brd, BarGraphDriver.sch]
2016-04-03 Cleaning
    Deleted duplicate files that weren't uploaded into the right folder.
    [BarGraphDriver.brd, BarGraphDriver.sch]
2016-04-03 New Boards
    Finished the first version of some new boards. They will need to be
    re-looked at when I'm less tired.
    [main_board.brd, main_board.sch, shoulder.brd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]
2016-04-03 Library
    Added my custom library for the USB3.0 connector breakout.
2016-04-03 Seven Segment Driver Boards
    LVSevenSegment is for low voltage displays like the Red display. It contains resistors to limit the current. The other design has no resistors. The design with resistors is surprisingly smaller than 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
    [LVSevenSegmentDriver.brd, LVSevenSegmentDriver.sch, SevenSegmentDriver.brd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]
2016-04-04 Ready for Fabbing
    Silk Screens added and last minute DRC checks done.
    [BarGraphDriver.brd, BarGraphDriver.sch, LVSevenSegmentDriver.brd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]
2016-04-04 Prep for oshpark
    Changed naming of BarGraphDriver to be more accurate, added a new bar
    graph driver for non-lv boards, fixed the usb breakout to match our
    standards and removed the text doc.
    [LVBarGraphDriver.brd, LVBarGraphDriver.sch, usb_breakout.brd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]
2016-04-04 Fixes
    Removed outer footprint of board so that each board is now the correct
    size instead of that of the default footprint.
    [BarGraphDriver.brd, LVBarGraphDriver.brd, LVSevenSegmentDriver.brd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]
2016-04-04 Minor fixes
    Added + and - on a few things to help differentiate what is what and
    when we need to flip the ribbon cable.
    [main_board.brd, shoulder.brd]
2016-04-05 aaaaaaaaaaaaaaaaaaaaaaaaaaaaaaaaaaaa
    Cleaned up schematics, replaced wire solder points with header pin
    mounts for standardization, recreated a broken file and dealt with the
    confusion and insanity that followed.
    [BarGraphDriver.brd, BarGraphDriver.sch, LVBarGraphDriver.brd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]
2016-04-05 FIRE TEH LAZOR!
    Modules for all your laser firing needs.
    [LaserModulev1.1.brd, LaserModulev1.1.sch]
2016-04-05 Super Fresh
    These boards are damn sexy.
    [LVSevenSegmentDriver.brd]
2016-04-05 New Lazer
    Changed some stuff in the laser module, nbd.
    [LaserModule.brd, LaserModule.sch]
2016-04-05 Fresher
    Last "super fresh" board wasn't fresh enough. Only real fix was
    assigning a via to a net and expanding the groundplane boundaries.
    [LVSevenSegmentDriver.brd]
2016-04-06 Fixes
    more fixes >:|
    should e ready for fabbing
    [BarGraphDriver.brd, LVBarGraphDriver.brd, LaserModule.brd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]
2016-04-06 moar fixes >:|
    I would say it's now ready to fab but who knows.
    [main_board.sch, shoulder.brd]
2016-04-15 Updates
    Disabled LED blink in the admin tool firmware, not sure about the other
    updates.
2016-04-26 Much Functionality Added
    New file containing lots of new functionality added. Kept the old for
    reference purposes.
    To be implemented:
    -Fire Modes
    -Display Update
    Other Functions should be tested for correct behavior
    [Laser_Tag_Firmware_2.0_In_Progress.ino.ino]
2016-04-28 Moar Functionality!
    This code should be working. It needs the display functions added so
    that it can display stuff.... Need to test with actual hardware to debug
    although software tests suggest that it can receive hits, kill player,
    track respawns, set new configurations.
    Supposedly, it can shoot and reload. Have not tested.
2016-04-29 Fixes and Functionality
    Fixed the shift by 8 instead of 4 for the admin tool (Greg was sleepy).
    Added functionality for shooting. The configure tagger function now
    creates a custom packet to send when the trigger is pressed ie. It can
    now shoot.
    (Fingers crossed)
    [Laser_Tag_Firmware_2.0_In_Progress.ino.ino, admin_tool.ino]
2016-04-29 Formatting and Comments
    Added a couple of comments
2016-05-01 Merges Jake's and Alan's code; Adds Support for Updating Displays
    Also gets rid of camel case. Sorry Alan. I miss it too. :/
2016-05-01 Adds Support for Team Colors. And it's Broken. -_-
    stupid obscure compiler errors
    [Laser_Tag_Firmware_2.0_In_Progress.ino.ino]
2016-05-01 Fixed Lots of BS
    Fixed GitHub going nuts and duplicating stuff. Fixed team_color issues
    by adding new function color_assigner. (This is a lazy hack fix)
    [Laser_Tag_Firmware_2.0_In_Progress.ino.ino]
2016-05-03 Cram time
    Updates to admin tool to help debug
    Small changes to the message format file to help figure out what's going
    on
    New firmware that removes most of the functionality of the main code,
    should only work with ltx taggers in ffa mode but for some reason the
    pulse data is not being sent correctly.
    [admin_tool.ino, greg_ver.ino]
2016-05-03 still dead
    Doesn't work for some reason. The data that is being given to the send
    function is not what is being received.
    [greg_ver.ino]

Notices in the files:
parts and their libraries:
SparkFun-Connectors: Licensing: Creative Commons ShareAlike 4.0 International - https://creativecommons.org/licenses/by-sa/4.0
